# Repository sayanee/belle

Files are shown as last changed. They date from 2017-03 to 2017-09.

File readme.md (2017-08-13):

# 🛎 belle

> Door bell with a buzzer and notification to IFTTT.

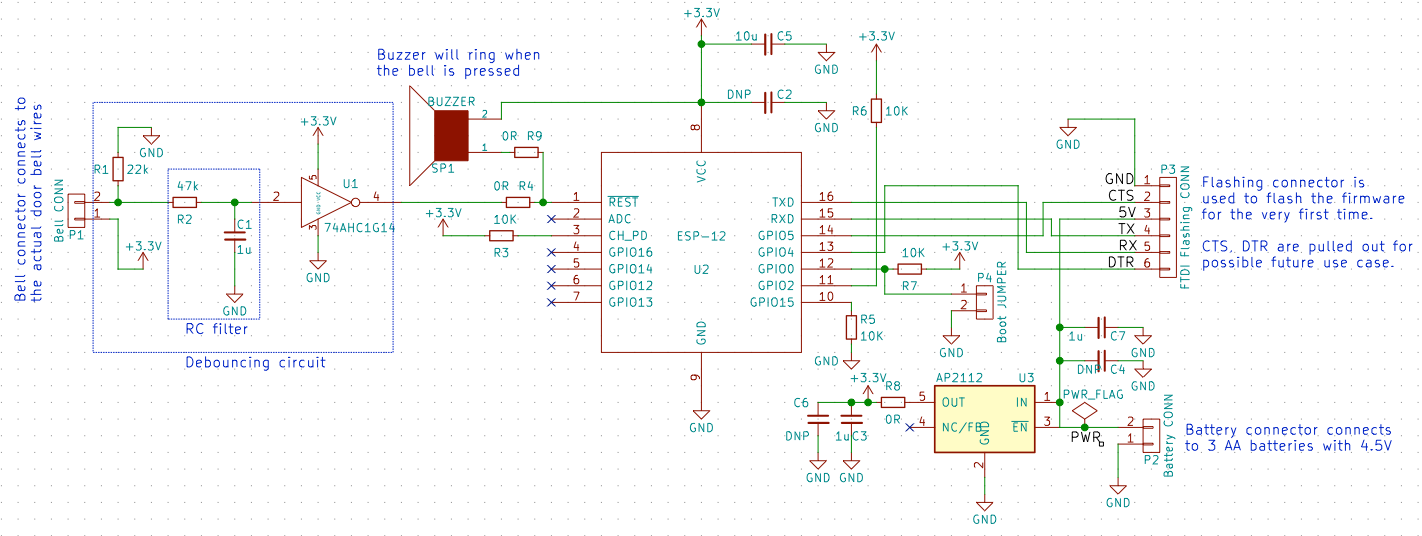
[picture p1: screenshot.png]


## Manufacture

1. Open [hardware](hardware) with [KiCad](http://kicad-pcb.org/)
1. Buy [Bill of Materials](bill_of_materials.csv)

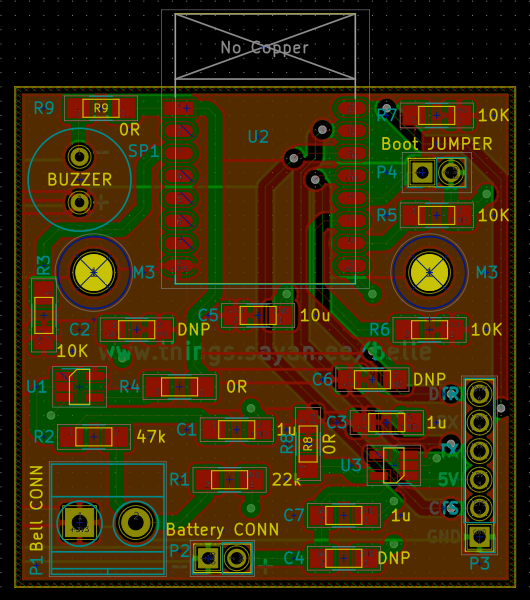
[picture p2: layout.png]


## Getting started

### Flash the firmware

1. Ensure the batteries are not connected yet!
1. Short the 2 header pins on `P4` for boot mode
1. Connect an FTDI chip to `P3`
1. Connect the other end of the FTDI chip to the laptop via USB

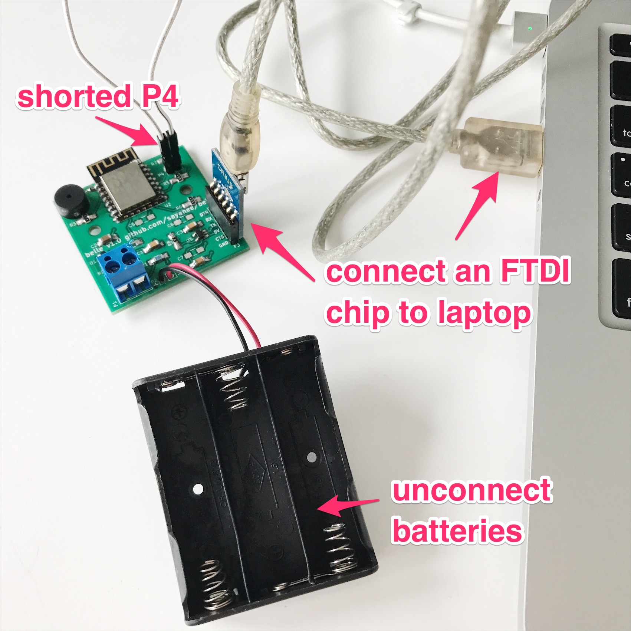
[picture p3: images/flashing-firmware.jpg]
    
1. Open Arduino IDE with the following configuration

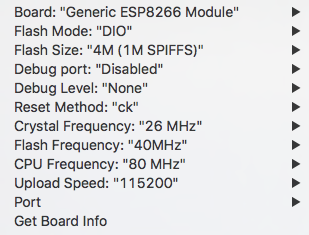
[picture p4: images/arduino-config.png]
    
1. Flash the [final firmware](firmware/belle.io) to the board
1. Remove the FTDI chip and the remove the shorted header pins of `P4`

### IFTTT

1. Configure IFTTT with [Webhooks](https://ifttt.com/maker_webhooks) and [Notification](https://ifttt.com/if_notifications) channels to Receive a web request
1. Put the event name as `bell_pressed`

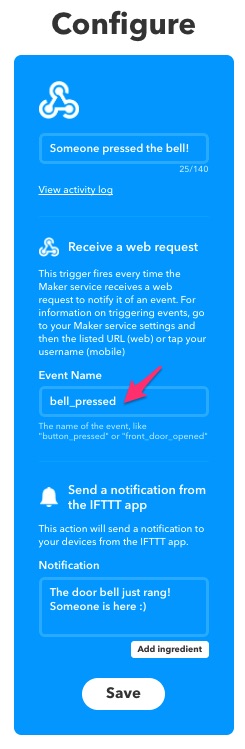
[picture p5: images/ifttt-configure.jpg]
    
1. Download the IFTTT app on mobile as well
1. Note the IFTTT key on the [maker_webhooks settings page](https://ifttt.com/services/maker_webhooks/settings)

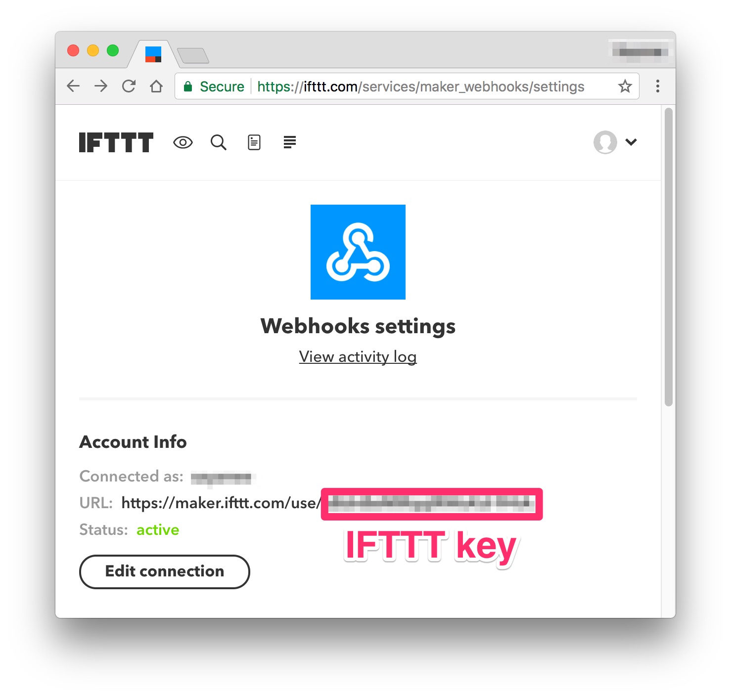
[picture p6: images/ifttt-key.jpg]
    

### Connect your door bell

1. Connect 3 AA batteries
1. Ensure the blue on-board LED is blinking fast
1. Connect your actual door bell to `P2` connectors
1. Mount it up on the wall

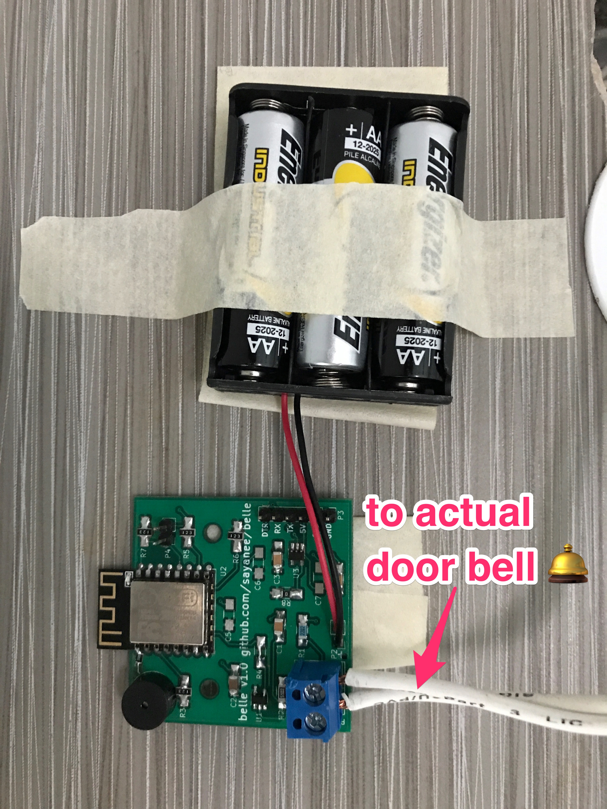
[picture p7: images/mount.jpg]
    
1. Connect to WiFi access point with SSID `Belle XXXX` and password `beautyandthebeast` on mobile / laptop
1. Visit page <http://belle.local>
1. Fill in `SSID`, `Password` and `IFTTT Key`

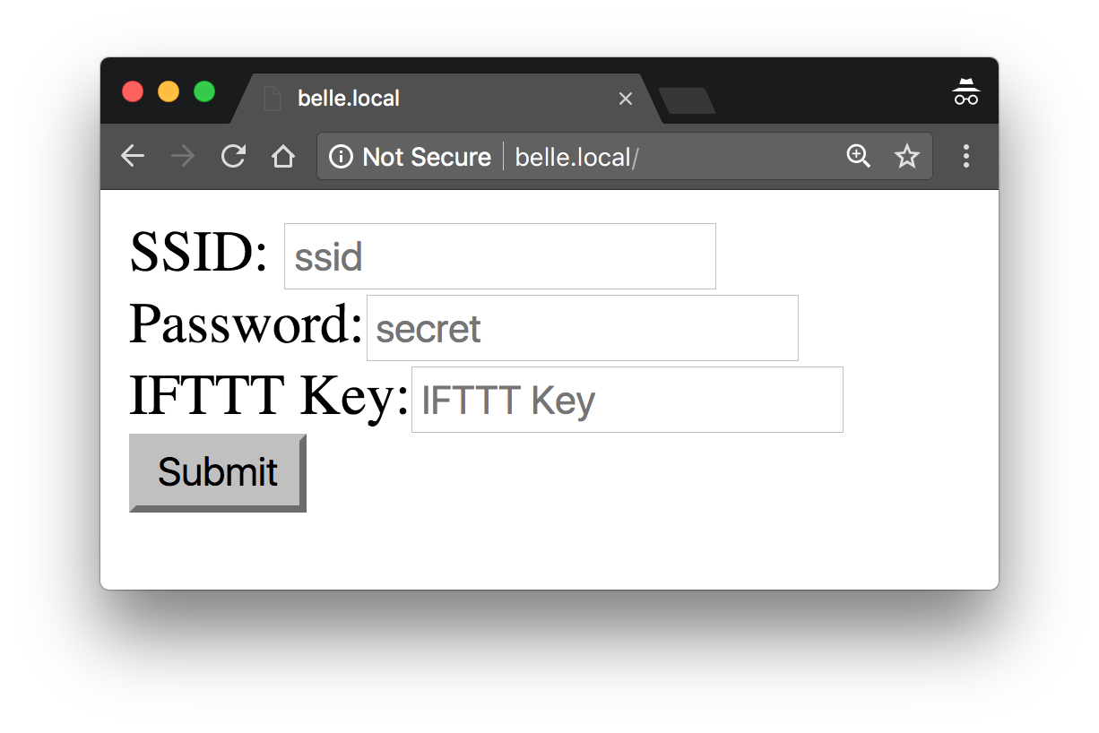
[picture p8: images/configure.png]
    
1. Wait for the LED to stop blinking
1. Press the 🛎
1. You should hear the buzzer and get a mobile IFTTT notification as well :tada:

## References :books:

### Power savings

1. [Power Saving tips for the ESP8266](https://github.com/z2amiller/sensorboard/blob/master/PowerSaving.md)
1. [SparkFun 3.3V Step-Up Breakout - NCP1402](https://www.sparkfun.com/products/10967)
1. [Sleeping the ESP8266](http://www.esp8266.com/wiki/doku.php?id=esp8266_power_usage)
1. [Reddit: How to actually run an ESP8266 for months on AA batteries](https://www.reddit.com/r/esp8266/comments/4gmkfl/how_to_actually_run_an_esp8266_for_months_on_aa/)
1. [Battery Powered ESP8266 IoT – Temperature Sensor](http://homecircuits.eu/blog/battery-powered-esp8266-iot-logger/)
1. [ESP8266 Sensor runs 17 days on a coin cell](https://www.youtube.com/watch?v=IYuYTfO6iOs)
1. [wifiwebservers - ESP8266 with 2AA batteries](http://www.arduinesp.com/wifiwebserver)
1. [Simple Authentication](https://github.com/esp8266/Arduino/blob/4897e0006b5b0123a2fa31f67b14a3fff65ce561/libraries/ESP8266WebServer/examples/SimpleAuthentification/SimpleAuthentification.in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)
1. [Debouncing circuit](http://www.ganssle.com/debouncing-pt2.htm)

### Flashing

1. [Programming ESP12](http://glyncowles.blogspot.sg/2015/07/programming-and-running-esp12-e.html)
1. [Troubleshooting flashing](https://learn.sparkfun.com/tutorials/esp8266-thing-hookup-guide/discuss#comment-55a05571ce395f88538b4567)
1. [NodeMCU modes](https://raw.githubusercontent.com/nodemcu/nodemcu-devkit/master/Documents/NODEMCU_DEVKIT_SCH.png)

## Tools :radio:

1. [simple calculator for estimating a (LiPo) battery's life](http://battery-life.of-things.de/battery-life-calculator.php)
1. [Encode to Base64 format](https://www.base64encode.org/)
1. [Electronics circuit simulator](http://www.falstad.com/circuit/)
1. [Circuit calculator](http://circuitcalculator.com/)

## Credits :pray:

:star: Big thanks to [Chinmay](https://chinmay.audio/), [Adnan](https://github.com/catmaker), [Kenneth](https://github.com/kennethlimcp), [Shan](https://twitter.com/shannietron), [Baoshi](https://twitter.com/ba0sh1) for prototyping, feedback, verifications and soldering :star:

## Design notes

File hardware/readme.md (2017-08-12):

# hardware continuity checklist

> Designed PCB layout with [KiCad](http://kicad-pcb.org/)

A list of connectivity checks after soldering

## Vcc (3.3V) - front

Reference: ESP8266 `Vcc` pin

- [x] `R3`, `R6`, `R7`, `R8`
- [x] `C2`, `C3`
- [x] `SP1` long pin
- [x] `P1` pin `1`
- [x] `U1` pin `6`
- [x] `U3`pin `5`

### Ground - back

Reference: ESP8266 `GND` pin

- [x] `R1`, `R5`
- [x] `C1`, `C2`, `C3`, `C4`, `C5`, `C6`, `C7`
- [x] `P2` Bell connector
- [x] `P3` FTDI connector
- [x] `P4` Boot jumper

## 5V

Reference: `P3` FTDI connector `5V`

- [x] `P2`
- [x] `C4`, `C7`
- [x] `U3` pins `1` and `3`

## Shorted pins?

- [x] `U1`, `U2` ESP8266, `U3`
- [x] `SP1`
- [x] `P1`, `P2`, `P3`, `P4`

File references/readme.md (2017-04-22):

# references

> commonly referenced pinout diagrams, schematic and other images

1. [Adafruit Huzzah schematic](https://cdn-learn.adafruit.com/assets/assets/000/024/745/original/adafruit_products_schem.png?1429900999)
1. [nodeMCU WeMos pinout](http://escapequotes.net/wp-content/uploads/2016/02/d1-mini-esp8266-board-sh_fixled.jpg)
1. [ESP12 pinout](https://acrobotic.com/media/wysiwyg/products/esp8266_esp12e_horizontal-01.png)

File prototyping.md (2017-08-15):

# Prototyping

> Photos of various prototypes

## 1. nodeMCU WeMos

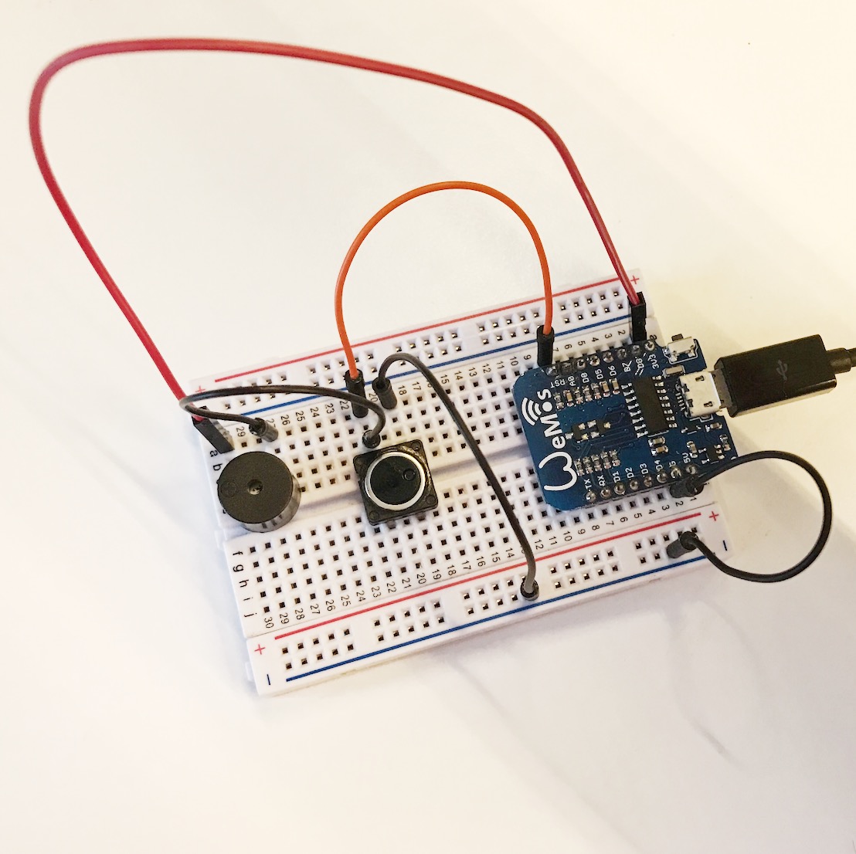
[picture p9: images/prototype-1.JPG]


- nodeMCU is used to test the initial circuit
- the circuit has a buzzer and a push button to mimc the bell

## 2. nodeMCU WeMos with Schmitt trigger

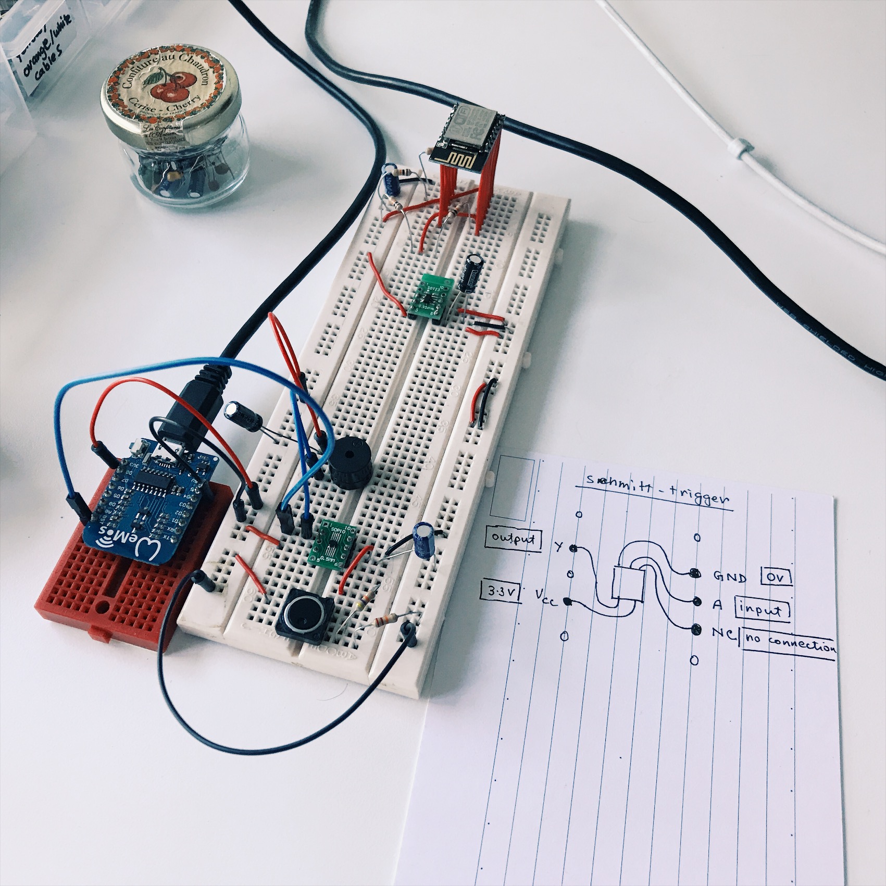
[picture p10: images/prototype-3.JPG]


- Super simple interrupt from sleep by pressing the bell

    ```c
    void setup() {
      Serial.begin(115200);
      pinMode(BUILTIN_LED, OUTPUT);

      Serial.println('Start');
      Serial.println('Wake up!');
      digitalWrite(BUILTIN_LED, HIGH);
      delay(1000);
      digitalWrite(BUILTIN_LED, LOW);
      delay(1000);
      digitalWrite(BUILTIN_LED, HIGH);
      delay(1000);
      digitalWrite(BUILTIN_LED, LOW);
      delay(1000);
    }

    void loop() {
      Serial.println("Sleeping in.... 3");
      delay(100);
      Serial.println("Sleeping in.... 2");
      delay(100);
      Serial.println("Sleeping in.... 1");
      delay(100);
      ESP.deepSleep(5e6, WAKE_RF_DEFAULT);
    }
    ```
- Connect to WiFi on waking up

    ```c
    #include <ESP8266WiFi.h>

    const char* ssid     = "secret"; // change secret
    const char* password = "secret"; // change secret

    void setup() {
      Serial.begin(115200);
      delay(10);

      Serial.println();
      Serial.println();
      Serial.print("Connecting to ");
      Serial.println(ssid);

      WiFi.begin(ssid, password);

      while (WiFi.status() != WL_CONNECTED) {
        delay(500);
        Serial.print(".");
      }

      Serial.println("");
      Serial.println("WiFi connected");
      Serial.println("IP address: ");
      Serial.println(WiFi.localIP());

      pinMode(LED_BUILTIN, OUTPUT);

      Serial.println('Start');
      Serial.println('Wake up!');
      digitalWrite(BUILTIN_LED, HIGH);
      delay(1000);
      digitalWrite(BUILTIN_LED, LOW);
      delay(1000);
      digitalWrite(BUILTIN_LED, HIGH);
      delay(1000);
      digitalWrite(BUILTIN_LED, LOW);
      delay(1000);
    }

    void loop() {
      Serial.println("Sleeping in.... 3");
      delay(100);
      Serial.println("Sleeping in.... 2");
      delay(100);
      Serial.println("Sleeping in.... 1");
      delay(100);
      ESP.deepSleep(5e6, WAKE_RF_DEFAULT);
    }
    ```
- Create a HTTP POST request to IFTTT

    ```c
    #include <ESP8266WiFi.h>

    const char* ssid     = "secret"; // change secret
    const char* password = "secret"; // change secret

    void setup() {
      Serial.begin(115200);
      delay(10);

      Serial.println();
      Serial.println();
      Serial.print("Connecting to ");
      Serial.println(ssid);

      WiFi.begin(ssid, password);

      while (WiFi.status() != WL_CONNECTED) {
        delay(500);
        Serial.print(".");
      }

      Serial.println("");
      Serial.println("WiFi connected");
      Serial.println("IP address: ");
      Serial.println(WiFi.localIP());

      pinMode(LED_BUILTIN, OUTPUT);

      Serial.println('Start');
      Serial.println('Wake up!');
      digitalWrite(BUILTIN_LED, HIGH);
      delay(1000);
      digitalWrite(BUILTIN_LED, LOW);
      delay(1000);
      digitalWrite(BUILTIN_LED, HIGH);
      delay(1000);
      digitalWrite(BUILTIN_LED, LOW);
      delay(1000);
      notifyBellPressed();
    }

    void loop() {
      Serial.println("Sleeping in.... 3");
      delay(100);
      Serial.println("Sleeping in.... 2");
      delay(100);
      Serial.println("Sleeping in.... 1");
      delay(100);
      ESP.deepSleep(5e6, WAKE_RF_DEFAULT);
    }

    void notifyBellPressed() {
      WiFiClientSecure client;

      if (!client.connect("maker.ifttt.com", 443)) {
        Serial.println("connection failed");
        return;
      }

      String PostData="sample";

      // Amend "{secret}" to IFTTT web request URL
      client.println("POST /trigger/bell_pressed/with/key/{secret} HTTP/1.1");
      client.println("Host:  maker.ifttt.com");
      client.println("User-Agent: nodeMCU/1.0");
      client.println("Connection: close");
      client.println("Content-Type: text/html; charset=utf-8;");
      client.print("Content-Length: ");
      client.println(PostData.length());
      client.println();
      client.println(PostData);

      return;
    }
    ```

## 3. ESP12

- Refactored to use ESP12 modules for ESP8266
- Also AP2112 is used for the voltage conversion from `5V` to `3.3V`

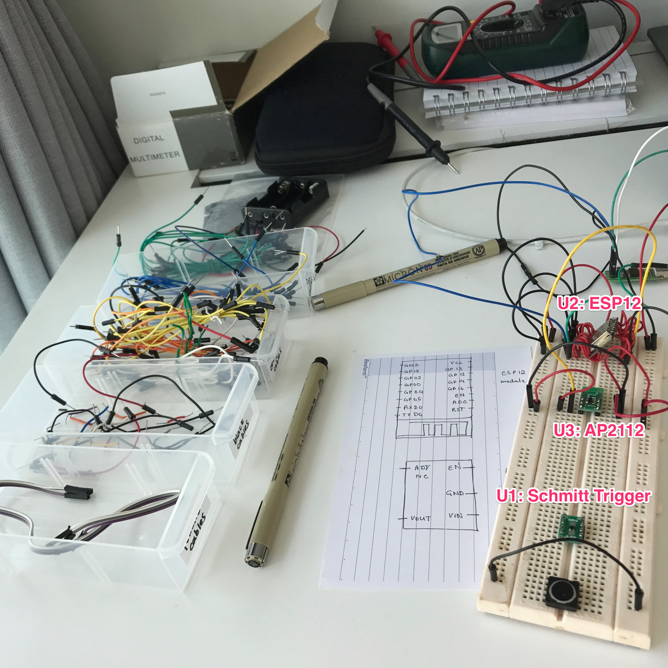
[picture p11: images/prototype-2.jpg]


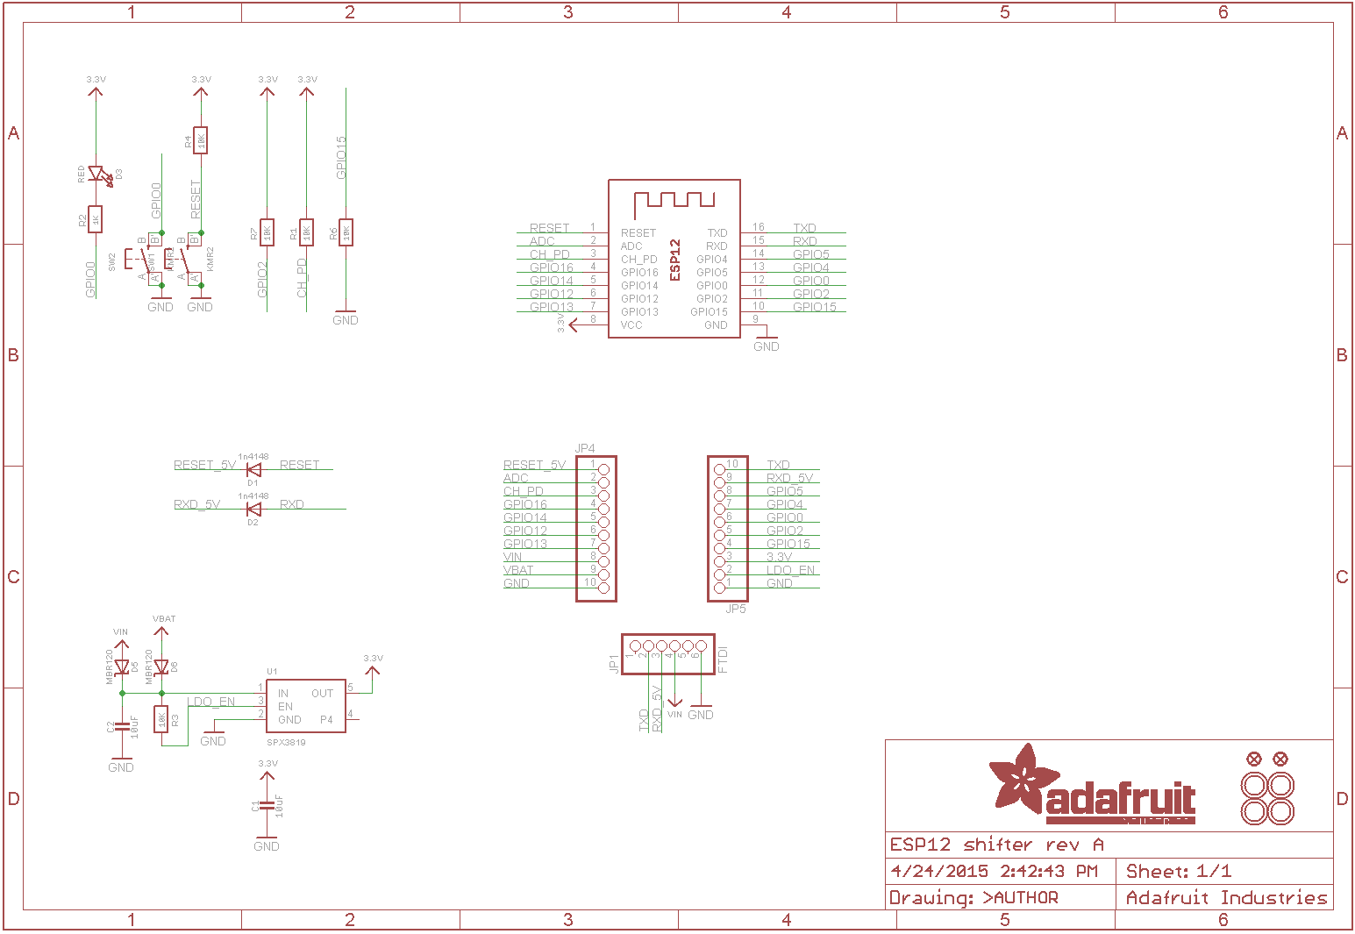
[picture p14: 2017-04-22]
references/adafruit_huzzah_shematic.png

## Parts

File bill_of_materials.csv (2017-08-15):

Value | Type | Designator | Q | Times | Package | URL to buy | AVL1 | AVL1 P/N | MOQ | Lead time (days) | Data sheet | Unit price | Total price
1 uF capacitor, ± 10% | Circuit component | C1, C3, C4 | 1 | 3 | SMD 1206 | http://sg.element14.com/multicomp/mcsh31b105k160ct/cap-mlcc-x7r-1uf-16v-1206/dp/1856638 | multicomp | MCSH31B105K160CT | 1 | 1 | http://www.farnell.com/datasheets/1825494.pdf | 0.033 | 0.099
10 uF capacitor, ± 10% | Circuit component | C2 | 1 | 1 | SMD 1206 | https://sg.element14.com/murata/grm31cr70j106ka01l/capacitor-10uf-6-3v/dp/4716711 | murata | GRM31CR70J106KA01L | 5 | 1 | https://www.farnell.com/datasheets/4390.pdf | 0.078 | 0.078
 | Circuit component | C5, C6, C7 | 1 | 3 | Do not populate
PCB Wire-to-Board Terminal block | Circuit component | P1 | 1 | 1 | Through-hole vertical | https://sg.element14.com/multicomp/ma522-500m02/terminal-block-eurostyle-2pos/dp/1708099 | multicomp | MA522-500M02 | 1 | 1 | https://www.newark.com/pdfs/datasheets/spc/Ta-1209.pdf | 0.323 | 0.323
Battery connector | Circuit component | P2 | 1 | 1 | Header pin straight 1x02 pitch 2.54mm
3 AA Battery holder | External component | connection to P2 | 1 | 1 | Size: approx. 56 x 45 x 15mm Weight: 15g | https://www.aliexpress.com/item/3-x-AA-Battery-Storage-Case-Plastic-Box-Holder-with-Cable-Lead-for-3-Packs-Standard/32571144192.html |  |  | 1 | 21 | nil | 1.1 | 1.1
Flashing connector | Circuit component | P3 | 1 | 1 | Header pin straight 1x06 pitch 2.54mm
22 KΩ resistor, ± 1%, 200V | Circuit component | R1 | 1 | 1 | SMD 1206 | https://sg.element14.com/koa-speer-electronics/rk73h2bttd2202f/res-thick-film-22k-1-0-25w-1206/dp/1812035 | Koa Speer | RK73H2BTTD2202F | 1 | 1 | https://www.farnell.com/datasheets/549017.pdf | 0.039 | 0.039
51 KΩ resistor, ± 1%, 200V, 0.25W | Circuit component | R2 | 1 | 1 | SMD 1206 | http://sg.element14.com/panasonic-electronic-components/erj8enf5102v/res-thick-film-51k-1-0-25w-1206/dp/2307743 | Panasonic | ERJ8ENF5102V | 20 | 1 | https://www.newark.com/pdfs/datasheets/spc/TA-677.pdf | 0.018 | 0.018
0Ω resistor, 1%, 0.25W | Circuit component | R4, R8 | 1 | 2 | SMD 1206 | http://sg.rs-online.com/web/p/surface-mount-fixed-resistors/2231981/?sra=pstk | TE Connectivity | CRG1206ZR | 50 |  | http://docs-asia.electrocomponents.com/webdocs/1397/0900766b81397505.pdf | 0.029 | 0.029
12 KΩ resistor, 1%, 200V, 0.25W | Circuit component | R3, R4, R5, R6, R7 | 1 | 5 | SMD 1206 | https://sg.element14.com/multicomp/mc1206s4f1002t5e/res-thick-film-10k-1-0-25w-1206/dp/1632523 | multicomp | MC1206S4F1002T5E | 1 | 1 | https://www.newark.com/pdfs/datasheets/spc/TA-677.pdf | 0.019 | 0.019
Buzzer Electro mechanical 5V DC | Circuit component | SP1 | 1 | 1 | Through hole | http://sg.element14.com/pro-signal/abi-050-rc/buzzer-electro-mechanical-5vdc/dp/2534976 | pro-signal | ABI-050-RC | 1 | 1 | https://www.farnell.com/datasheets/2032394.pdf | 3.29 | 3.29
Inverter, Schmitt Trigger, 2V to 5.5V | Circuit component | U1 | 1 | 1 | SOT-23-5 | https://sg.element14.com/texas-instruments/sn74ahc1g14dbvr/74ahc-single-gate-smd-74ahc1g14/dp/1105919 | Texas Instruments | SN74AHC1G14DBVR | 1 | 1 | https://www.farnell.com/datasheets/1860943.pdf | 0.664 | 0.664
ESP8266 SMT module | Circuit component | U2 | 1 | 1 | SMT | https://www.adafruit.com/product/2491 | Adafruit | ESP12 | 1 | 28 | https://cdn-shop.adafruit.com/product-files/2471/0A-ESP8266__Datasheet__EN_v4.3.pdf | 2.688 | 2.688
CMOS process low dropout linear voltage regulator | Circuit component | U3 | 1 | 1 | SOT-23 | http://sg.rs-online.com/web/p/low-dropout-voltage-regulators/8283509/ | BCD semiconductor | AP2112 | 1 | 1 | https://cdn-shop.adafruit.com/product-files/2471/AP2112.pdf | 0.197 | 0.197
 |  |  | 14 | 22 |  |  |  |  |  |  |  | SGD | 8.515

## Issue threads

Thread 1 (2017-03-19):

layout changes

sayanee, 2017-03-19:
- [x] move the bell connector right to the edge
- [x] move the battery connecter to the edge
- [x] layout component next to each other similar to the schematic
  - for debugging
  - for shorter traces
- [x] add silkscreen with url and version
- [x] label bell connector and battery connector pins
- [x] label flashing connector pins

Closed 2017-03-19.

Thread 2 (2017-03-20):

position of ESP modules

sayanee, 2017-03-20:
soldering

> Is the esp module going to be soldered on the board or headers will be used! I have seen cases where the antennas failed to worked when radio modules are soldered on like an SMT with a no copper area. More considerations will be required if the module is soldered on directly.

position

> it'd be nice if ESP12 antenna was right up to edge of your PCB with some copper clearance (5mm) to left&right&top&underneath of antenna pattern. And pls move the R5 away from the antenna.

sayanee, 2017-03-20:
[Adafruit Huzzah](https://learn.adafruit.com/adafruit-huzzah-esp8266-breakout/downloads) shows the layout of the ESP12 module

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

sayanee, 2017-05-09:
closed with https://github.com/sayanee/belle/commit/2d6acd98b846e6787d95b16f563462086defe06c

Closed 2017-05-09.

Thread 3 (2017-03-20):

capacitor

sayanee, 2017-03-20:
values

> your decoup caps C2 C3 C4 -- i know these are the datasheets' basic recommendations, but it doesn't hurt to make them slightly larger, especially this is a "one-off" prototype you're building. It'd be nice if C4 is `47-100uF`, and C2 is `47uF`. It's just a feeling 'cos ppl have issues during the early prototypes around the esp8266.

add more capacitors:

1. AP2112 pin `OUT` and pin `IN` with additional `1nF`
1. ESP pin `VCC` with additional `1nF`

shannietron, 2017-03-21:
Since you have a fair bit of space in the PCBs, you can add empty pads for capacitors in parallel to the other decoupling caps. So that in the future if you encounter issues and want to add a decoupling cap, it is easy to do.

Closed 2017-05-01.

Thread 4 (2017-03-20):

add notes to the schematic

sayanee, 2017-03-20:
> I don't understand what you're trying to make of the speaker, it's connected to the REST (reset?) line. Did that work in your prototype?

Closed 2017-03-20.

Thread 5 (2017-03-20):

flashing connector

sayanee, 2017-03-20:
> Is P3 configured to any of your usual USB-Serial adapters pinout?

standard from [dfrobot](https://www.dfrobot.com/)

notthetup, 2017-03-20:
For example : https://www.dfrobot.com/product-581.html

There seem to be a couple of "standards".

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

sayanee, 2017-03-21:
sticking to the original pin layout

sayanee, 2017-05-01:
Decided to use the standard connector (related to #14) using FTDI chip

Closed 2017-05-01.

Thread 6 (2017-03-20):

interchange the bell connectors

sayanee, 2017-03-20:
> I'm a little confused. When you press the button. It pulls the line low. Which means, after the Schmidt inverter, it's going to be high. Generally, reset pins are active  low. I'm not sure about the esp though. And Your speaker logic is inverted. When the button is pressed, the output of the Schmidt trigger is high, so the speaker sees 3.3V at both pins. So it won't sound. And it will always beep when not pressed

## Actual result

Truth table

| Bell | Schmidt (in) | Schmidt (out) | RST | ESP | Bell rings
| ------ | ------ | ------ | ------ | ------ | ------ |
| close | 0 | 1 | 1 | Normal | No ring
| open | 1 | 0 | 0 | RST | Bell rings

## Expected result

Truth table

| Bell | Schmidt (in) | Schmidt (out) | RST | ESP |
| ------ | ------ | ------ | ------ | ------ |
| close | 1 | 0 | 0 | RST
| open | 0 | 1 | 1 | normal

shannietron, 2017-03-20:
If you are going to continue sinking current through the inverter, it'll be way easier to just ground the other pin of the buzzer.

sayanee, 2017-03-21:
Related to #8

sayanee, 2017-07-10:
From [ESP8266 System Description](https://espressif.com/en/support/download/documents) Version 2.2, 2017

> Pin32 serves as an RST pin which can be left floating when it is not used. The reset pin is held low when the chip is enabled. In order to avoid resets caused by external interference, the lead is generally required to be short, and no external pull-up resistor is necessary.

Closed 2017-05-01.

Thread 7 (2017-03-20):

fix vias and trace width dimensions

sayanee, 2017-03-20:
> a small problem in the PCB. Via's diameter is too small. Typical board house will need 0.15mm on both sides of the hole, so minimum you need via size = hole size + 0.3mm

notthetup, 2017-03-20:
Check with your fab house, what trace sizes and via sizes they can do.

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

sayanee, 2017-05-09:
closed with https://github.com/sayanee/belle/commit/2d6acd98b846e6787d95b16f563462086defe06c

Closed 2017-05-09.

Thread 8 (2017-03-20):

current sinking issue

sayanee, 2017-03-20:
> one thing needs attention is if 74HC14 is able to sink enough current from the buzz. From datasheet the buzz max need 30mA, 74HC has max in/out current of 25mA, a bit tight

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

> use a small resistor to isolate. because the speaker may create some nasty spikes

Closed 2017-05-01.

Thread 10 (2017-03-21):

Add Mounting Holes

shannietron, 2017-03-21:

sayanee, 2017-05-04:
- Front view of the 3 AA battery holder
    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
- Back of the 3 AA battery holder
    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
- M3 screw head
    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
- Separated by `3cm`

sayanee, 2017-05-09:
closed with https://github.com/sayanee/belle/commit/2d6acd98b846e6787d95b16f563462086defe06c

Closed 2017-05-09.

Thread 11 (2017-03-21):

add battery holder for 3 AA batteries in BOM

sayanee, 2017-03-21:
Related to the position of mounting holes in the future #10

sayanee, 2017-03-21:
closed with [BOM](https://docs.google.com/spreadsheets/d/1m9wsQ8mQkDeZknwRr8GEDQU02FGcmrBqXRizbyn6Ccs/pubhtml)

Closed 2017-03-21.

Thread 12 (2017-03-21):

Silkscreen Layers During Gerber Generation

shannietron, 2017-03-21:
Ensure the correct layers are picked during gerber generation. Right now, the top silkscreen layer looks like this. Things like V1.0 didn't show up.

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

Another option is to move text you want in the silkscreen to the silkscreen layer.

sayanee, 2017-05-09:
closed with https://github.com/sayanee/belle/commit/2d6acd98b846e6787d95b16f563462086defe06c

Closed 2017-05-09.

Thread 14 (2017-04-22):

Unable to flash with ESP12F modules

sayanee, 2017-04-22:
## Steps to reproduce

1. Wire up an `ESP12F module` (taking reference from [Huzzah schematic](https://cdn-learn.adafruit.com/assets/assets/000/024/745/original/adafruit_products_schem.png?1429900999))
    - `GND` to `0V`
    - `GPIO15` to `0V`  via a `10kΩ` resistor
    - `GPIO2` to `3V3`  via a `10kΩ` resistor
    - `GPIO0` to `0V`  via a `10kΩ` resistor
    - `GPIORX` to `TX` on serial
    - `GPIOTX` to `RX` on serial
    - `VCC` to `3V3`
    - `CHPD` to `3V3`
    - `RST` the chip by connecting rest to `0V` briefly before flashing
    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
1. Connect to the MacBook via the [serial console cable](https://www.adafruit.com/product/954)
1. Open up Arduino IDE to flash a blinky program

    ```c
    void setup() {
      pinMode(LED_BUILTIN, OUTPUT);
    }

    void loop() {
      digitalWrite(LED_BUILTIN, LOW);           
      delay(1000);           
      digitalWrite(LED_BUILTIN, HIGH);
      delay(2000);
    }
    ```

    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

## Actual result

1. Turn on the serial monitor
1. Reset ESP12
1. Upload the program
1. Arduino is having an error when flashing

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

## Expected result

1.  Turn on the serial monitor in Arduino IDE
1. Reset ESP12
1. Serial monitor should show `waiting for download`
1. Arduino should be successful in flashing the blinky progam

sayanee, 2017-04-22:
@shannietron any idea? 🤔

notthetup, 2017-04-22:
Instructions from Adafruit for flashing firmware.

Maybe GPIO0 can't be tied to ground all the time. https://learn.adafruit.com/adafruit-huzzah-esp8266-breakout/using-arduino-ide

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

sayanee, 2017-04-22:
> turn on serial monitor then reset, can you see something like 'waiting for download'?

nope, nothing

> that's not right. even if not enter program made there need be something. maybe check serial connection?

sayanee, 2017-04-25:
Wired it like Huzzah and the serial monitor gives:

```sh
Fatal exception (0): epc1=0x40100003, epc2=0x00000000, epc3=0x00000000, excvaddr=0x00000000, depc=0x00000000
```

sayanee, 2017-05-01:
# Solution

1. Use a proper [FTDI chip](https://world.taobao.com/item/13702527783.htm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)
1. Be careful of shorting ESP12 module pins while soldering

sayanee, 2017-05-02:
## Normal mode

> serial monitor output

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

## Boot mode

> serial monitor output

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

notthetup, 2017-06-29:
https://github.com/esp8266/esp8266-wiki/wiki/Boot-Process#esp-boot-modes

sayanee, 2017-06-30:
| GPIO15 | GPIO0 | GPIO2 | Mode | Description | Binary | Decimal
| ------ | ------ | ------ | ------ | ------ | ------ | ------
| L | L | H | UART | Download code from UART | 001 | 1
| L | H | H | Flash | Boot from SPI Flash | 011 | 3
| H | x | x | SDIO | Boot from SD-card | 100, 101, 110, 111 | 4, 5, 6, 7

sayanee, 2017-07-01:
See [edited solution](https://github.com/sayanee/belle/issues/14#issuecomment-298308491)

Closed 2017-07-01.

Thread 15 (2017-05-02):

Total dimension of the edge cut PCB should be less than the 3 AA battery holder

sayanee, 2017-05-02:
- dimension of 3 AA battery holder: `4.5cm` by `5.8cm`
- proposed dimension of the PCB: `4.5cm` by `4.5cm`
- antenna position is external to the PCB ([example](http://hackaday.com/2016/09/15/esp32-hands-on-awesome-promise/))

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

sayanee, 2017-05-09:
closed with https://github.com/sayanee/belle/commit/2d6acd98b846e6787d95b16f563462086defe06c

Closed 2017-05-09.

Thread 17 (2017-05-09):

arrange R3 for easy soldering and rework

sayanee, 2017-05-09:
> R3 can probably be between buzzer and the m3 hole. Makes it easier for the iron tip to reach the esp12 pads if rework is needed.

sayanee, 2017-05-10:
closed with #18

Closed 2017-05-10.

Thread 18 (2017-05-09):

DFM tweaks

kennethlimcp, 2017-05-09:
1. R3 can be rotated 90 degrees and placed between M3 mounting hole and buzzer.

  This would aid soldering of ESP-12 pads and makes any reworking easier.

2. Board information can be moved upwards to avoid last "e" in `sayanee` from overlapping with via

3. M3 label can be placed nearer to NTPH holes

4. Via is too closed to bottom trace (blue arrow)

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

5. There seems to be an issue with the top copper pour set to "+3v3"?

Usually the planes are tied to ground instead of a voltage, unless you are working with >2 layer boards where a layer is required to connect components to 3v3/5v.

If this is switched, there will be lesser vias with R4, C1, R1, C4, C7, C3, C6, C2 all having one side of the pad connected to the ground plane directly.

sayanee, 2017-05-10:
- [ ] move up board information
- [ ] place M3 label nearer to NPTH
- [ ] move via near the LDO

sayanee, 2017-05-10:
@kennethlimcp

> There seems to be an issue with the top copper pour set to "+3v3"

In the current design, the top layer is `3V3 and bottom layer is `GND`. If I switch them around, there seems to be around an equal number of vias for `3V3` instead of `GND`.

Closed 2017-05-10.

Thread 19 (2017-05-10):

R4 might be too large value

sayanee, 2017-05-10:
> When U1 output low, buzzer is turned on. Is R4 10K too large?

> when button is pressed, U1 output low, buzz turn on, the potential at right side of R4 is not low enough to bring ESP into reset

sayanee, 2017-05-10:
Try it out on the manufactured PCB with a `10k` and swap out with other values if this value does not work. Either there is no effect on the PCB layout / footprint.

sayanee, 2017-07-25:
Confirmed that `R4` needs to be almost `0Ω`

Closed 2017-07-25.

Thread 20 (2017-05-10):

experiment if 2AA works without an LDO

sayanee, 2017-05-10:
put a `0Ω` resistor so that the same PCB layout can be used for both 3AA with LDO and 2AA without LDO

sayanee, 2017-07-25:
Closed with https://github.com/sayanee/hippo/issues/5

Closed 2017-07-25.

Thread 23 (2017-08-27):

Mounting designs

sayanee, 2017-08-27:
1. Solder wire from PCB's battery wire connectors to the battery holder
1. Screw PCB and battery holder onto the acrylic sheet
1. Attach an acrylic sheet to the wall with [3m Mushroom Dual Lock Self Adhesive Tape](https://www.alibaba.com/product-detail/3m-SJ3551-400-Mushroom-Dual-Lock_292520038.html)

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

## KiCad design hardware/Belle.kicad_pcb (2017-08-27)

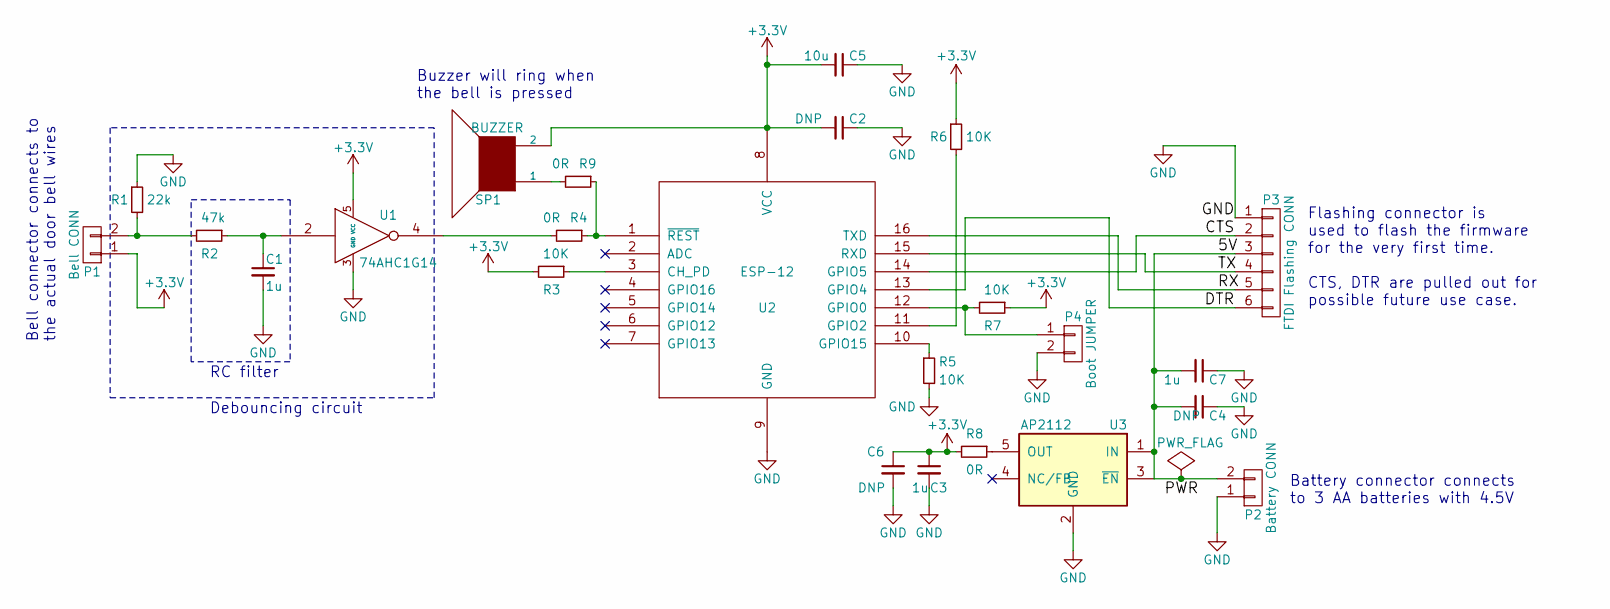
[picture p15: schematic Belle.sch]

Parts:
C1, C3, C7: 1u; C_1206_HandSoldering
C2, C4, C6: DNP; C_1206_HandSoldering
C5: 10u; C_1206_HandSoldering
P1: Bell CONN; TerminalBlock_Pheonix_MKDS1.5-2pol
P2: Battery CONN; Pin_Header_Straight_1x02_Pitch2.54mm
P3: FTDI Flashing CONN; Pin_Header_Straight_1x06_Pitch2.54mm
P4: Boot JUMPER; Pin_Header_Straight_1x02_Pitch2.54mm
R1: 22k; R_1206_HandSoldering
R2: 47k; R_1206_HandSoldering
R3, R5, R6, R7: 10K; R_1206_HandSoldering
R4, R8, R9: 0R; R_1206_HandSoldering
SP1: BUZZER; prosignal_buzzer
U1: 74AHC1G14; SOT-23-5_HandSoldering
U2: ESP-12
U3: AP2112; SOT-23-5_HandSoldering

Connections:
+3V3: C2.2, C3.1, C5.2, C6.1, P1.1, R3.2, R6.1, R7.1, R8.2, SP1.2, U1.5 (VCC), U2.8 (VCC)
/5V: C4.2, C7.2, P2.2, P3.3, U3.1 (IN), U3.3 (~EN~)
/CTS: P3.2, U2.14 (GPIO5)
/DTR: P3.6, U2.13 (GPIO4)
/RX: P3.5, U2.16 (TXD)
/TX: P3.4, U2.15 (RXD)
GND: C1.2, C2.1, C3.2, C4.1, C5.1, C6.2, C7.1, P2.1, P3.1, P4.2, R1.1, R5.2, U1.3 (GND), U2.9 (GND), U3.2 (GND)
unnamed: C1.1, R2.1, U1.2
unnamed: P1.2, R1.2, R2.2
unnamed: P4.1, R7.2, U2.12 (GPIO0)
unnamed: R3.1, U2.3 (CH_PD)
unnamed: R4.1, R9.1, U2.1 (~REST)
unnamed: R4.2, U1.4
unnamed: R5.1, U2.10 (GPIO15)
unnamed: R6.2, U2.11 (GPIO2)
unnamed: R8.1, U3.5 (OUT)
unnamed: R9.2, SP1.1

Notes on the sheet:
Buzzer will ring when the bell is pressed
Flashing connector is used to flash the firmware for the very first time. CTS, DTR are pulled out for possible future use case.
Bell connector connects to the actual door bell wires
Battery connector connects to 3 AA batteries with 4.5V
RC filter
Debouncing circuit

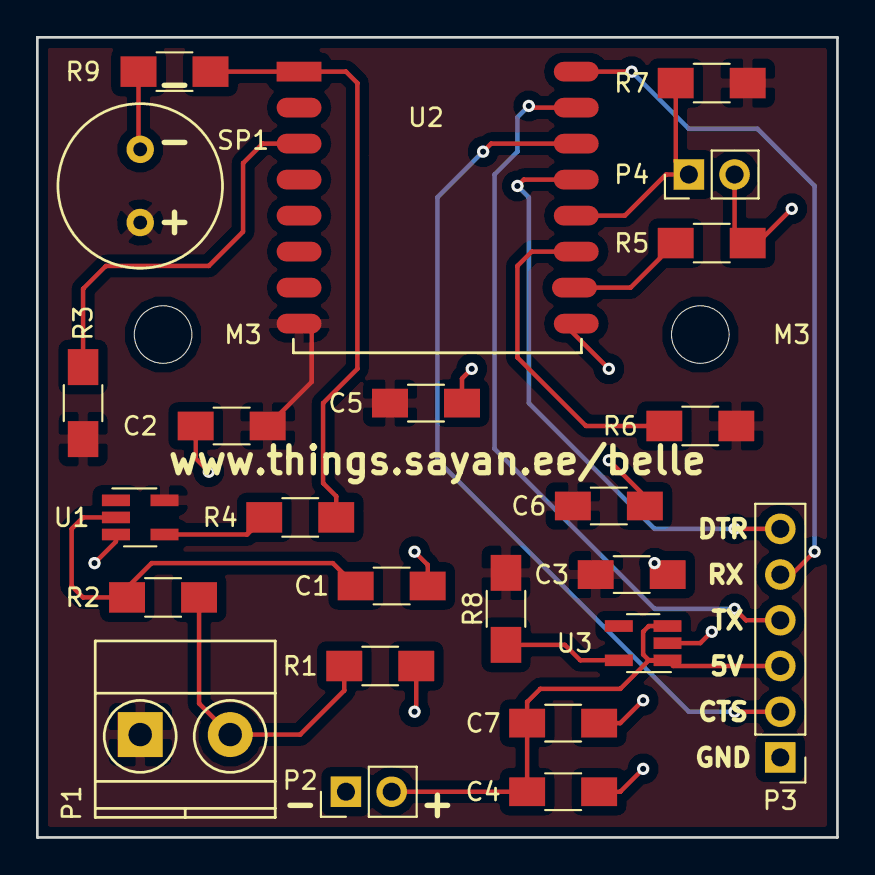
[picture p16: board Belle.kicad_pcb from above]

Board: 2 copper layers, 44.4 x 44.5 mm, 26 parts (0 on the bottom side), 17 nets.

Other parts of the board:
M3, M3#2: MountingHole_3.2mm_M3

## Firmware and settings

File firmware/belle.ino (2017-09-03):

// INFO:
// Connect to "Bell XXX" Access Point for initial configuration at http://belle.local
// Get IFTTT key at https://ifttt.com/services/maker_webhooks/settings
// Send HTTP POST to IFTTT only when waking up from deep sleep

#define WAKE_UP_REASON_DEEP_SLEEP 5
#define WAKE_UP_REASON_EXTERNAL_SYSTEM_RESET 6
#define LED 2
#define BELL_PRESS_ADDR 30
#define IS_BELL_PRESSED EEPROM.read(BELL_PRESS_ADDR)

#include <ESP8266WiFi.h>
#include <WiFiClient.h>
#include <ESP8266WebServer.h>
#include <ESP8266mDNS.h>
#include <EEPROM.h>

extern "C" {
  #include "user_interface.h"
}

String AP_NamePrefix = "Belle ";
const char WiFiAPPSK[] = "beautyandbeast";
const char* DomainName = "belle"; // set domain name domain.local
char ssid [50] = "";
char password [50] = "";
String key = "";
const char* host = "maker.ifttt.com";
const int httpsPort = 443;

ESP8266WebServer server(80);

void setup() {
  EEPROM.begin(512);

  if (getResetReason() == WAKE_UP_REASON_DEEP_SLEEP && IS_BELL_PRESSED == 0) {
    recordBellPressEvent();
  }

  // GPIO02 on ESP-12 module is linked to on-board LED
  pinMode(LED, OUTPUT);
	Serial.begin(115200);

  if (!hasWiFiCredentials()) {
    setupAP();
  }
}

void loop() {
  Serial.println();

  if (!hasWiFiCredentials()) {
    blink(200);
    Serial.println("[INFO] WiFi is not configured!");
    Serial.println("[INFO] Connect to 'Belle XXX' WiFi and visit http://belle.local/");
    server.handleClient();
  } else {
    blink(2000);

    if (connectToWiFi() == true) {
      if (getResetReason() == WAKE_UP_REASON_DEEP_SLEEP || getResetReason() == WAKE_UP_REASON_EXTERNAL_SYSTEM_RESET) {
        if (IS_BELL_PRESSED == 1) {
          sendToIFTTT();
          eraseBellPressEvent();
        }
      }
    }

    goToSleep();
  }
}

void goToSleep() {
  Serial.println("");
  Serial.println("[INFO] Sleeping in 2");
  delay(100);
  Serial.println("[INFO] Sleeping in 1");
  delay(100);

  ESP.deepSleep(0, WAKE_RF_DEFAULT);
}

void sendToIFTTT() {
  Serial.println("[INFO] Sending IFTTT notification...");
  WiFiClientSecure client;

  if (!client.connect(host, httpsPort)) {
    Serial.println("[ERROR] Connection failed");
    return;
  }

  // Get the "secret" from https://ifttt.com/services/maker_webhooks/settings
  String url = "/trigger/bell_pressed/with/key/";
  key = readKey();

  client.print(String("GET ") + url + key + " HTTP/1.1\r\n" +
               "Host: " + host + "\r\n" +
               "User-Agent: ESP8266\r\n" +
               "Connection: close\r\n\r\n");

  unsigned long timeout = millis();
  while (client.available() == 0) {
    if (millis() - timeout > 5000) {
      Serial.println("[ERROR] Client Timeout!");
      client.stop();
      return;
    }
  }

  while(client.available()){
    String line = client.readStringUntil('\r');
    Serial.print(line);
  }

  return;
}

int getResetReason() {
  rst_info* ri = system_get_rst_info();
  if (ri == NULL) {
    return -1;
  }

  // REASON_DEFAULT_RST		= 0,	/* normal startup by power on */
	// REASON_WDT_RST			= 1,	/* hardware watch dog reset */
	// REASON_EXCEPTION_RST	= 2,	/* exception reset, GPIO status won’t change */
	// REASON_SOFT_WDT_RST   	= 3,	/* software watch dog reset, GPIO status won’t change */
	// REASON_SOFT_RESTART 	= 4,	/* software restart ,system_restart , GPIO status won’t change */
	// REASON_DEEP_SLEEP_AWAKE	= 5,	/* wake up from deep-sleep */
	// REASON_EXT_SYS_RST      = 6		/* external system reset */

  return ri->reason;
}

bool hasWiFiCredentials() {
  if (WiFi.SSID() == "") {
    return false;
  }

  return true;
}

void blink(int interval) {
  digitalWrite(LED, HIGH);
  delay(interval);

  digitalWrite(LED, LOW);
  delay(interval);
}

bool connectToWiFi() {
  int count = 0;
  while (WiFi.status() != WL_CONNECTED) {
    delay(500);
    Serial.print(".");
    count++;

    if (count % 10 == 0) {
      Serial.println("");
    }

    if (count > 120) {
      Serial.println("[ERROR] Could not connect to WiFi. Please try again.");
      return false;
    }
  }

  return true;
}

void setupAP() {
  Serial.println("[TRACE] Configuring access point");
  WiFi.mode(WIFI_AP);

  String AP_NameString = getAPName();

  // convert String to char array
  char AP_NameChar[AP_NameString.length() + 1];
  memset(AP_NameChar, 0, AP_NameString.length() + 1);

  for (int i=0; i<AP_NameString.length(); i++)
    AP_NameChar[i] = AP_NameString.charAt(i);

  WiFi.softAP(AP_NameChar, WiFiAPPSK);

  startMDNS();
  startServer();
  Serial.println("[INFO] Started access point!");
}

String getAPName() {
  uint8_t mac[WL_MAC_ADDR_LENGTH];
  WiFi.softAPmacAddress(mac);
  String macID = String(mac[WL_MAC_ADDR_LENGTH - 2], HEX) +
                 String(mac[WL_MAC_ADDR_LENGTH - 1], HEX);
  macID.toUpperCase();
  return AP_NamePrefix + macID;
}

void startMDNS() {
  if (!MDNS.begin(DomainName)) {
    Serial.println("[ERROR] MDNS responder did not setup");
    while(1) {
      delay(1000);
    }
  }

  MDNS.addService("http", "tcp", 80);
}

void startServer() {
  server.on("/", handleRoot);

  const char * headerkeys[] = {"User-Agent","Cookie"} ;
  size_t headerkeyssize = sizeof(headerkeys)/sizeof(char*);

  server.collectHeaders(headerkeys, headerkeyssize );
  server.begin();
}

void handleRoot() {
  if (server.hasArg("ssid") && server.hasArg("password")){
    Serial.print("[INFO] SSID:");
    Serial.println(server.arg("ssid"));
    server.arg("ssid").toCharArray(ssid, 50);

    Serial.print("[INFO] Password received!");
    server.arg("password").toCharArray(password, 50);

    Serial.println("[INFO] IFTTT key received!");
    writeKey(server.arg("key"));
    readKey();

    if (server.arg("key") == readKey()) {
      WiFi.begin(ssid, password);
      WiFi.persistent(true);
      WiFi.setAutoConnect(true);
      WiFi.setAutoReconnect(true);

      int count = 0;
      while (WiFi.status() != WL_CONNECTED) {
        delay(500);
        Serial.print(".");
        count++;

        if (count % 10 == 0) {
          Serial.println("");
        }

        if (count > 120) {
          Serial.println("[ERROR] Could not connect to WiFi. Please try again.");
          WiFi.disconnect();
          setupAP();
          break;
        }
      }

      if (WiFi.status() == WL_CONNECTED) {
        Serial.println("");
        Serial.print("[INFO] WiFi connected! IP address: ");
        Serial.println(WiFi.localIP());

        server.sendHeader("Location","/");
        server.sendHeader("Cache-Control","no-cache");
        server.sendHeader("Set-Cookie","ESPSESSIONID=1");
        server.send(301);

        return;
      }
    }
  }

  String content = "<html><body><form action='/' method='post'>";
  content += "SSID: <input type='text' name='ssid' placeholder='ssid'><br>";
  content += "Password:<input type='password' name='password' placeholder='secret'><br>";
  content += "IFTTT Key:<input type='text' name='key' placeholder='IFTTT Key'><br>";
  content += "<input type='submit' name='submit' value='Submit'></form></body></html>";
  server.send(200, "text/html", content);
}

void writeKey(String writeStr) {
  delay(10);

  for (int i = 0; i < writeStr.length(); ++i) {
    EEPROM.write(i, writeStr[i]);
  }

  EEPROM.commit();
}

String readKey() {
  String readStr;
  char readChar;

  // TODO: Store length of key
  for (int i = 0; i < 22; ++i) {
    readChar = char(EEPROM.read(i));
    readStr += readChar;
  }

  return readStr;
}

void recordBellPressEvent() {
  EEPROM.write(BELL_PRESS_ADDR, 1);
  EEPROM.commit();
}

void eraseBellPressEvent() {
  EEPROM.write(BELL_PRESS_ADDR, 0);
  EEPROM.commit();
}

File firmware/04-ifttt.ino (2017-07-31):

// INFO:
// Wakeup on bell press
// Send HTTP POST to IFTTT only when waking up from deep sleep
// PREPARE:
// Edit "secret"s in Line 17, 18, 88
// Connect an external button to the connector

#define WAKE_UP_REASON_DEEP_SLEEP 5

#include <ESP8266WiFi.h>

extern "C" {
  #include "user_interface.h"
}

// Edit "secret" ssid and password below
const char* ssid = "secret";
const char* password = "secret";
const char* host = "maker.ifttt.com";
const int httpsPort = 443;

void setup() {
  // GPIO02 on ESP-12 module is linked to on-board LED
  pinMode(2, OUTPUT);

  Serial.begin(115200);
  delay(10);

  Serial.println();
  Serial.println();
  Serial.print("Connecting to ");
  Serial.println(ssid);

  WiFi.begin(ssid, password);

  while (WiFi.status() != WL_CONNECTED) {
    delay(500);
    Serial.print(".");
  }

  Serial.println("");
  Serial.print("IP address: ");
  Serial.println(WiFi.localIP());
}

void loop() {
  int wakeupReason = getWakeupReason();

  digitalWrite(2, HIGH);
  Serial.println(WiFi.localIP());
  delay(500);

  digitalWrite(2, LOW);
  delay(500);

  digitalWrite(2, HIGH);
  delay(500);

  digitalWrite(2, LOW);
  delay(500);

  if (wakeupReason == WAKE_UP_REASON_DEEP_SLEEP) {
    Serial.println("Making a request to IFTTT...");
    httpPost();
  }

  digitalWrite(2, HIGH);
  Serial.println("Sleep.... 2");
  delay(500);

  digitalWrite(2, LOW);
  Serial.println("Sleep.... 1");
  delay(500);

  // sleep indefinitely until wakeup
  ESP.deepSleep(0, WAKE_RF_DEFAULT);
}

void httpPost() {
  WiFiClientSecure client;

  if (!client.connect(host, httpsPort)) {
    Serial.println("connection failed");
    return;
  }

  // Get the "secret" from https://ifttt.com/services/maker_webhooks/settings
  String url = "/trigger/bell_pressed/with/key/secret";

  client.print(String("GET ") + url + " HTTP/1.1\r\n" +
               "Host: " + host + "\r\n" +
               "User-Agent: ESP8266\r\n" +
               "Connection: close\r\n\r\n");

  unsigned long timeout = millis();
  while (client.available() == 0) {
    if (millis() - timeout > 5000) {
      Serial.println("[ERROR] Client Timeout!");
      client.stop();
      return;
    }
  }

  while(client.available()){
    String line = client.readStringUntil('\r');
    Serial.print(line);
  }

  Serial.println("[INFO] Closing connection");
  return;
}

int getWakeupReason() {
  rst_info* ri = system_get_rst_info();
  if (ri == NULL) {
    return -1;
  }

  // REASON_DEFAULT_RST       = 0,  /* normal startup by power on */
  // REASON_WDT_RST           = 1,  /* hardware watch dog reset */
  // REASON_EXCEPTION_RST     = 2,  /* exception reset, GPIO status won’t change */
  // REASON_SOFT_WDT_RST      = 3,  /* software watch dog reset, GPIO status won’t change */
  // REASON_SOFT_RESTART      = 4,  /* software restart ,system_restart , GPIO status won’t change */
  // REASON_DEEP_SLEEP_AWAKE  = 5,  /* wake up from deep-sleep */
  // REASON_EXT_SYS_RST       = 6   /* external system reset */

  return ri->reason;
}

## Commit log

2017-03-05 remove BOM heading until it is there
2017-03-05 include ESP8266 library
    [Belle.sch]
2017-03-19 add gerbers
    [_saved_Belle.sch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]
2017-03-19 edit schematic
2017-03-19 regenerated gerbers
    [Belle.kicad_pcb, Belle.sch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]
2017-03-19 edit layout. close #1
    [Belle.kicad_pcb, Belle.sch, _saved_Belle.sch]
2017-03-20 add notes to the schematic. close #4
    [Belle.sch]
2017-03-21 rename speaker to buzzer. close #9
    [Belle.kicad_pcb, Belle.sch]
2017-03-21 add ESP12 module in BOM and datasheet. close #13
2017-04-14 add circuit simulator as a tool
2017-04-19 interchange bell connectors #6
    [Belle.sch]
2017-04-19 add code for simple interrupt from sleep
2017-04-25 add 10k resistor between RESET and Smidth Trigger output
    [Belle.sch]
2017-05-01 add extra capacitors. close #3
    [Belle.sch]
2017-05-01 arrange flashing connector as default FTDI pin. close #5
    [Belle.sch]
2017-05-02 re-generate net list based on new schematic
    [Belle.kicad_pcb, Belle.sch]
2017-05-03 generate bill of materials
    [Belle.sch]
2017-05-03 rename datasheet accordingly to BOM
2017-05-03 rename resistors in order of schematic placement
    [Belle.sch]
2017-05-04 initial rat's nest. #2 #10
    [Belle.kicad_pcb]
2017-05-09 layout PCB
    [Belle.kicad_pcb]
2017-05-09 adjust decoupling capacitors
    [Belle.kicad_pcb]
2017-05-09 add labels for battery connecter
    [Belle.kicad_pcb, _saved_Belle.sch]
2017-05-09 add gerber files
    [Belle-B.Cu.gbr, Belle-B.Mask.gbr, Belle-B.SilkS.gbr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]
2017-05-09 add board info on the silkscreen. close #16
    [Belle-B.Cu.gbr, Belle-B.Mask.gbr, Belle-B.SilkS.gbr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]
2017-05-10 add dfm tweaks. #18
    [Belle.kicad_pcb, Belle.sch, _saved_Belle.sch]
2017-05-10 modifiec PCB
    [Belle.kicad_pcb, Belle.sch, _saved_Belle.sch]
2017-05-14 add new gerber generated files
    [Belle-B.Cu.gbr, Belle-B.Mask.gbr, Belle-B.SilkS.gbr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]
2017-06-12 add bom as csv file
    [bill_of_materials.csv]
2017-06-13 move the mounting hoel slightly. close #21
    [Belle.kicad_pcb]
2017-06-13 edit bom
    [bill_of_materials.csv]
2017-06-17 correct labelling of ground and power
    [Belle.kicad_pcb]
2017-07-12 add annotations for buzzer
    [Belle.kicad_pcb]
2017-07-13 update screenshot with buzzer pin annotations
2017-07-25 add sleep and wakeup interrupt
2017-07-26 remove unused pinMode for LED_BUILTIN
2017-07-31 add error checking for http get to ifttt
    [04-ifttt.ino]
2017-08-12 add wiring continuity checklist
2017-08-12 add shorted pin check
2017-08-13 fix IFTTT key reading after reset
    [07-belle.ino]
2017-08-13 refactor pin 2 to a #define
2017-08-13 clean up serial prints
2017-08-13 remove more serial prints
2017-08-13 update bom prices
    [bill_of_materials.csv]
2017-08-14 add test for wakeup on reset
    [test.ino]
2017-08-15 add 3 0Ω resistors to schematic and bom
    [Belle.sch, bill_of_materials.csv]
2017-08-20 Add R9 0R resistor to layout
    [_saved_Belle.sch]
2017-08-20 Save KiCad
    [Belle.kicad_pcb, Belle.sch, _saved_Belle.sch]
2017-08-21 Update new layout and schematic diagrams
2017-08-21 Generate GERBERS
    [Belle-B.Cu.gbr, Belle-B.Mask.gbr, Belle-B.SilkS.gbr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]
2017-08-27 Remove through hole for ESP-12F module. close #22
2017-08-27 Save project
    [Belle.kicad_pcb]
2017-08-27 Save KiCad project
    [Belle.sch]
2017-09-02 Add instructions to press the button to test
2017-09-02 Add new lines in print statements
2017-09-03 Send to IFTTT after multiple short presses that detects reset from external system
    [belle.ino]
